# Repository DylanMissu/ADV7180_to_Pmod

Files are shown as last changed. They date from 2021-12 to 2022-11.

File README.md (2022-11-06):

# ADV7180_to_Pmod
These are pcb files for an analog camera block interface board based on the adv7180.

This board takes in analog video and outputs a digital ITU-R BT.656 video signal to the pmod ports. This can then be processed by an FPGA or a fast enough processor.

## Schematic

Schematic for the video converter.
Schematic

## Pictures

| Front | Back |
|---|---|
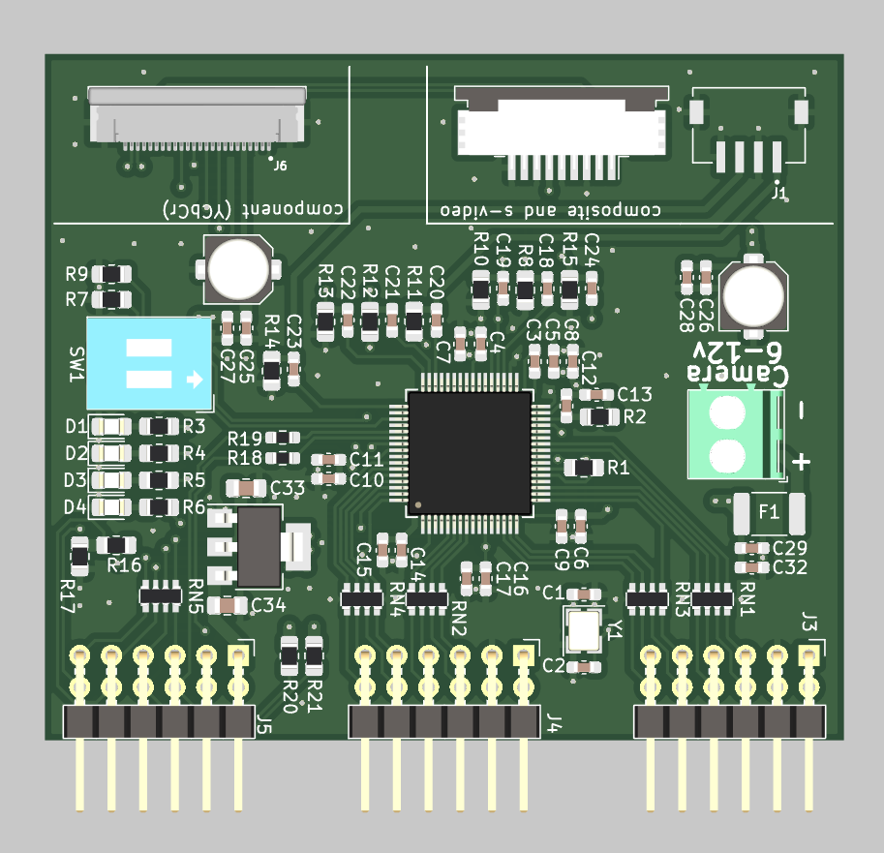
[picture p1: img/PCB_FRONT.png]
front
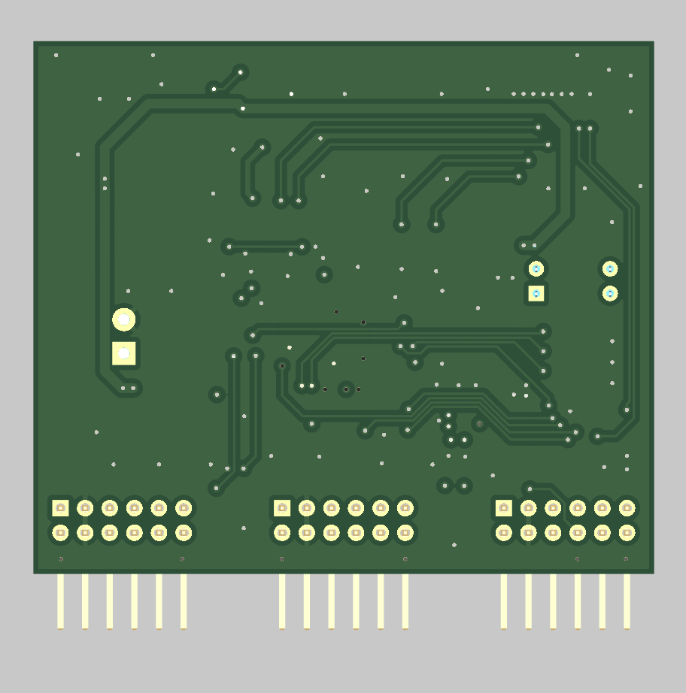
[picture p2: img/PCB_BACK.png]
back
| |  |

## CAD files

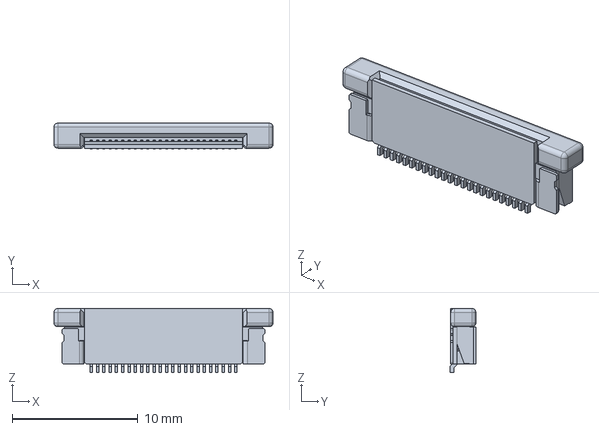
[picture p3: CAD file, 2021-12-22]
footprints/2-1734592-4/2-1734592-4.step
17.4 x 2.05 x 5.11 mm

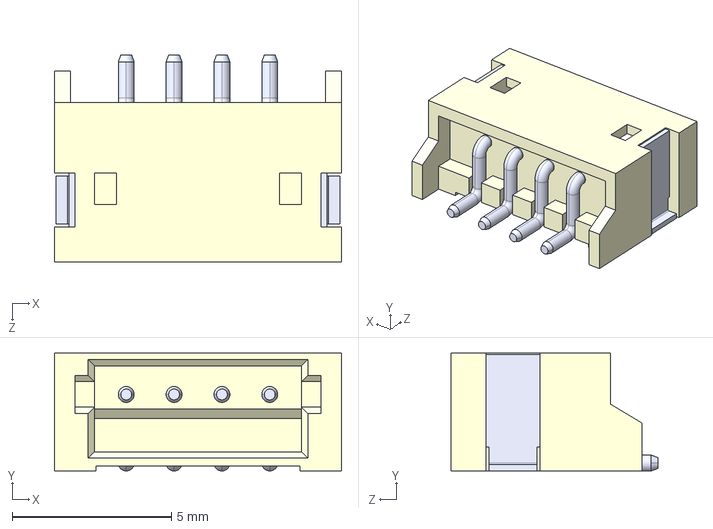
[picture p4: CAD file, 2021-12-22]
step/S4B-ZR-SM4A-TF-LF--SN---3DModel-STEP-56544.STEP
9.00 x 3.70 x 6.50 mm

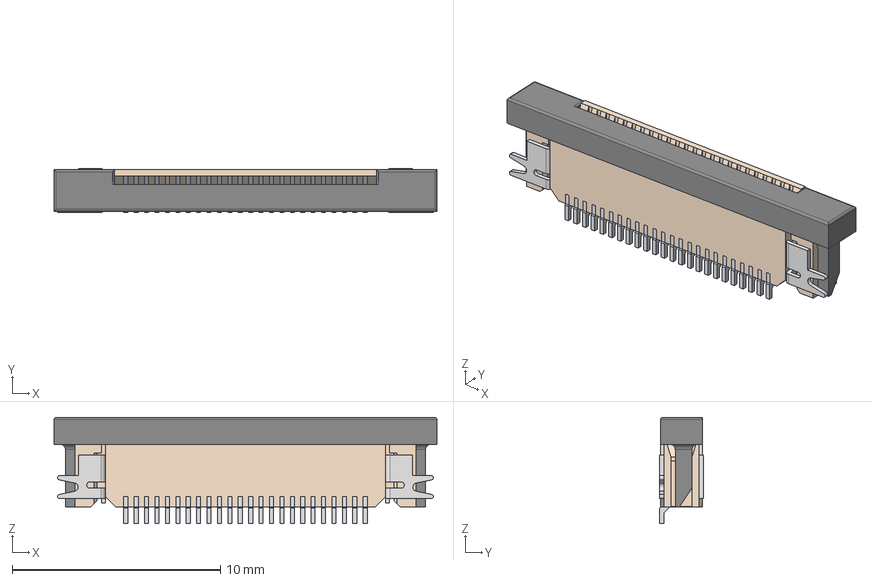
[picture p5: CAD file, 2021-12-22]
step/68712414022.stp
18.4 x 2.10 x 5.10 mm

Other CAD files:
step/2-1734592-4.stp

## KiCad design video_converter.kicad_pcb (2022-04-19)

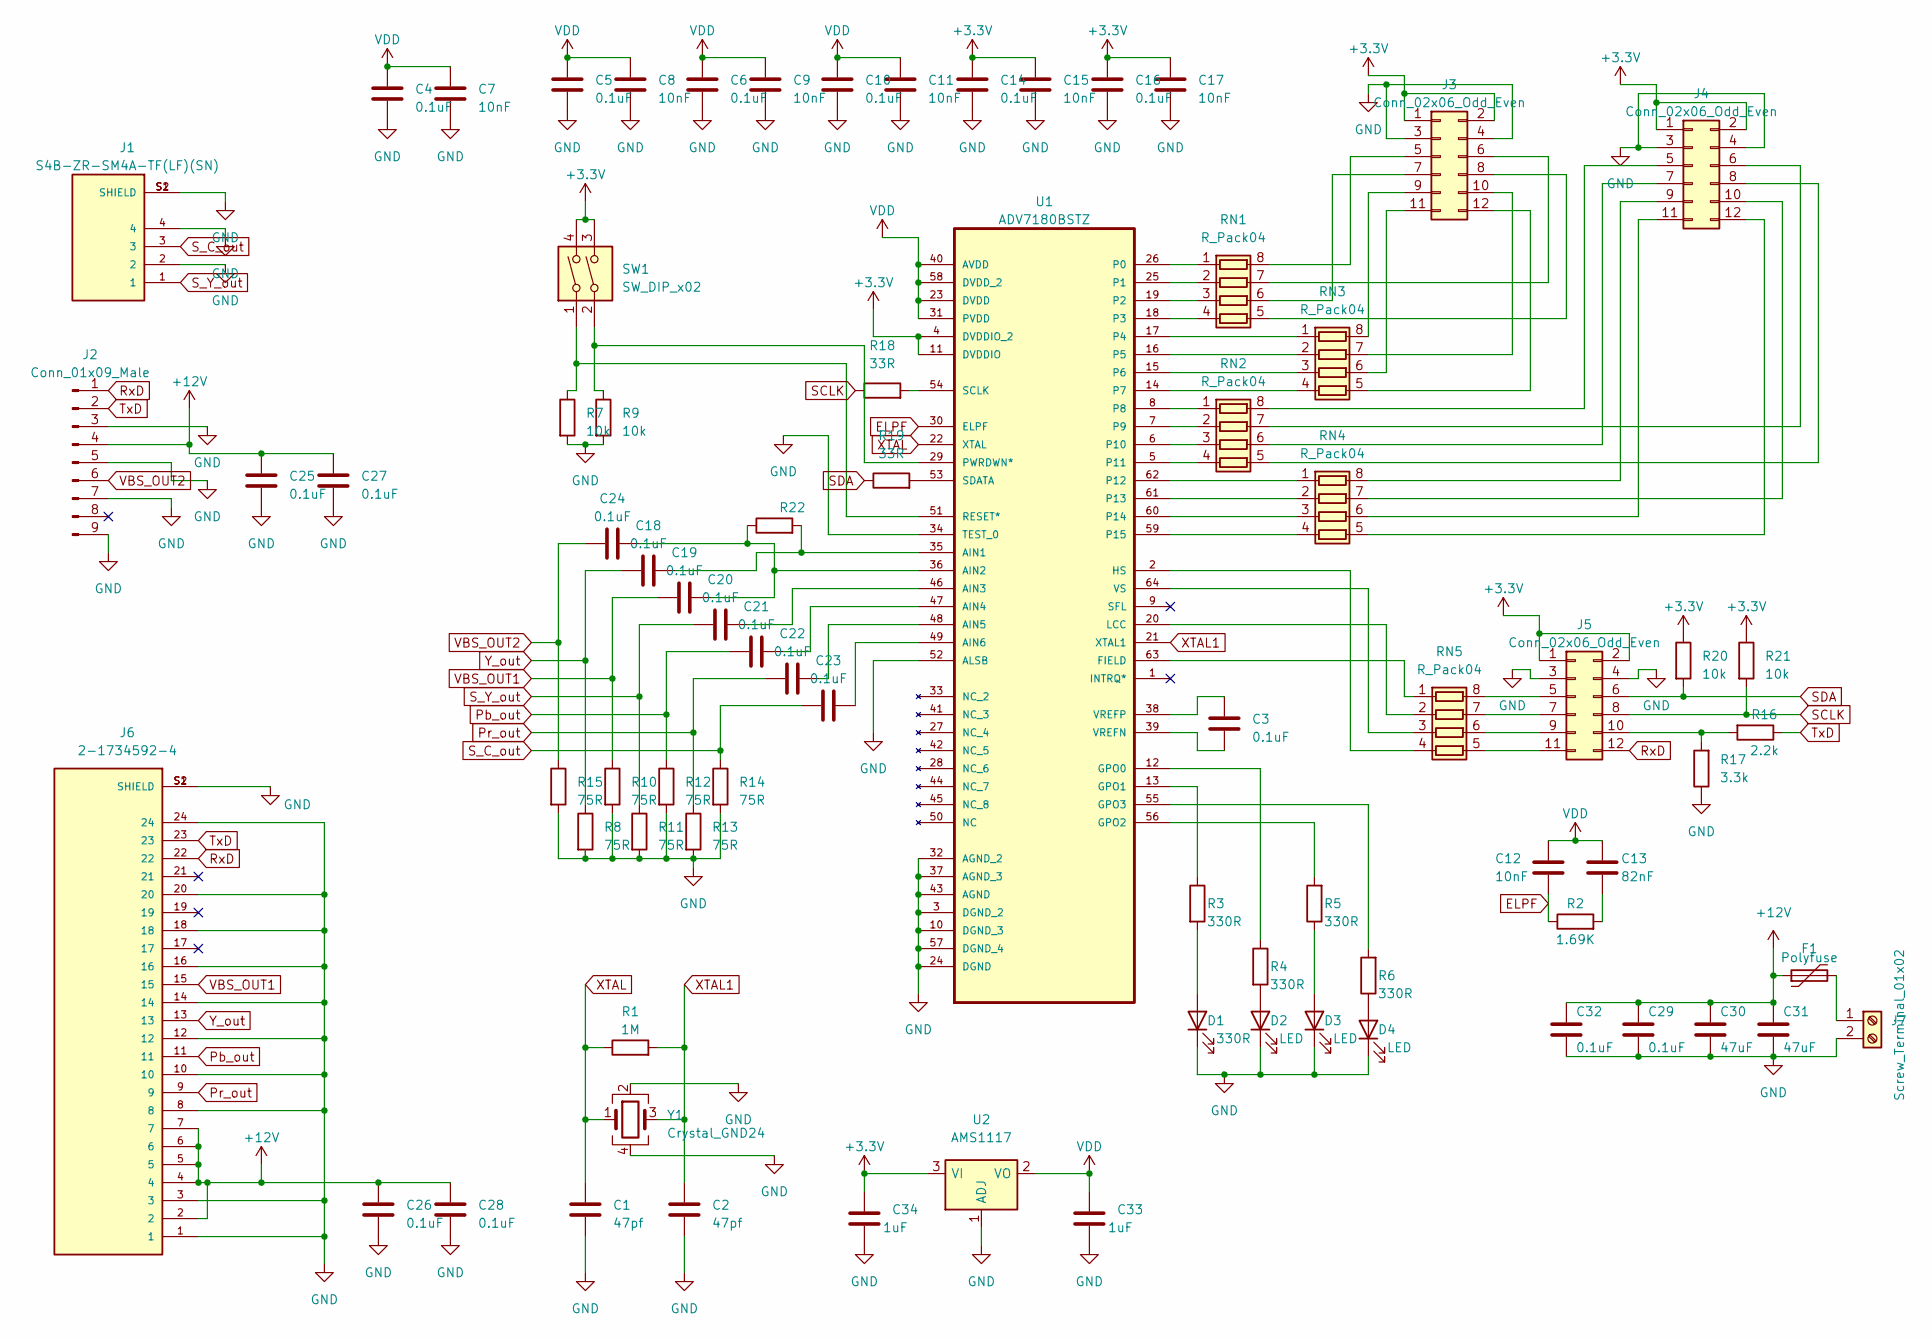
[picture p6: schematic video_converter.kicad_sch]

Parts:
C1, C2: 47pf; C_0603_1608Metric_Pad1.08x0.95mm_HandSolder
C3, C4, C5, C6, C10, C14, C16, C18, C19, C20, C21, C22, C23, C24, C25, C26, C27, C28, C29, C32: 0.1uF; C_0603_1608Metric_Pad1.08x0.95mm_HandSolder
C7, C8, C9, C11, C12, C15, C17: 10nF; C_0603_1608Metric_Pad1.08x0.95mm_HandSolder
C13: 82nF; C_0603_1608Metric_Pad1.08x0.95mm_HandSolder
C30, C31: 47uF; C_Elec_5x5.4
C33, C34: 1uF; C_0805_2012Metric_Pad1.18x1.45mm_HandSolder
D1: 330R; LED_0805_2012Metric_Pad1.15x1.40mm_HandSolder
D2, D3, D4: LED; LED_0805_2012Metric_Pad1.15x1.40mm_HandSolder
F1: Polyfuse; Fuse_1812_4532Metric_Pad1.30x3.40mm_HandSolder
J1: S4B-ZR-SM4A-TF(LF)(SN); JST_S4B-ZR-SM4A-TF(LF)(SN); PARTREV N/A
J2: Conn_01x09_Male; TE_84952-9_1x09-1MP_P1.0mm_Horizontal
J3, J4, J5: Conn_02x06_Odd_Even; PinHeader_2x06_P2.54mm_Horizontal
J6: 2-1734592-4; TE_2-1734592-4; PARTREV C
J7: Screw_Terminal_01x02; TerminalBlock_Phoenix_PT-1,5-2-3.5-H_1x02_P3.50mm_Horizontal
R1: 1M; R_0805_2012Metric_Pad1.20x1.40mm_HandSolder
R2: 1.69K; R_0805_2012Metric_Pad1.20x1.40mm_HandSolder
R3, R4, R5, R6: 330R; R_0805_2012Metric_Pad1.20x1.40mm_HandSolder
R7, R9, R20, R21: 10k; R_0805_2012Metric_Pad1.20x1.40mm_HandSolder
R8, R10, R11, R12, R13, R14, R15: 75R; R_0805_2012Metric_Pad1.20x1.40mm_HandSolder
R16: 2.2k; R_0805_2012Metric_Pad1.20x1.40mm_HandSolder
R17: 3.3k; R_0805_2012Metric_Pad1.20x1.40mm_HandSolder
R18, R19: 33R; R_0603_1608Metric_Pad0.98x0.95mm_HandSolder
R22: (no value)
RN1, RN2, RN3, RN4, RN5: R_Pack04; R_Array_Convex_4x0603
SW1: SW_DIP_x02; SW_DIP_SPSTx02_Slide_9.78x7.26mm_W7.62mm_P2.54mm
U1: ADV7180BSTZ; QFP50P1200X1200X160-64N; MPN ADV7180BSTZ
U2: AMS1117; SOT-223-3_TabPin2
Y1: Crystal_GND24; Crystal_SMD_Abracon_ABM8G-4Pin_3.2x2.5mm

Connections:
+3V3: C14.1, C15.1, C16.1, C17.1, C34.1, J3.1, J3.2, J4.1, J4.2, J5.1, J5.2, R20.1, R21.1, SW1.3, SW1.4, U1.4 (DVDDIO_2), U1.11 (DVDDIO), U2.3 (VI)
+12V: C25.1, C26.1, C27.1, C28.1, C29.1, C30.1, C31.1, C32.1, F1.1, J2.4, J6.2, J6.4, J6.5, J6.6, J6.7
ELPF: C12.1, R2.1, U1.30 (ELPF)
GND: C1.2, C2.2, C4.2, C5.2, C6.2, C7.2, C8.2, C9.2, C10.2, C11.2, C14.2, C15.2, C16.2, C17.2, C25.2, C26.2, C27.2, C28.2, C29.2, C30.2, C31.2, C32.2, C33.2, C34.2, D1.1 (K), D2.1 (K), D3.1 (K), D4.1 (K), J1.2, J1.4, J1.S1 (SHIELD), J1.S2 (SHIELD), J2.3, J2.5, J2.7, J2.9, J3.3, J3.4, J4.3, J4.4, J5.3, J5.4, J6.1, J6.3, J6.8, J6.10, J6.12, J6.14, J6.16, J6.18, J6.20, J6.24, J6.S1 (SHIELD), J6.S2 (SHIELD), J7.2, R7.2, R8.2, R9.2, R10.2, R11.2, R12.2, R13.2, R14.2, R15.2, R17.1, U1.3 (DGND_2), U1.10 (DGND_3), U1.24 (DGND), U1.32 (AGND_2), U1.34 (TEST_0), U1.37 (AGND_3), U1.43 (AGND), U1.52 (ALSB), U1.57 (DGND_4), U2.1 (ADJ), Y1.2, Y1.4
unnamed: C3.1, U1.38 (VREFP)
unnamed: C3.2, U1.39 (VREFN)
unnamed: C13.1, R2.2
unnamed: C18.2, R22.2, U1.35 (AIN1)
unnamed: C19.2, C24.2, R22.1, U1.36 (AIN2)
unnamed: C20.2, U1.46 (AIN3)
unnamed: C21.2, U1.47 (AIN4)
unnamed: C22.2, U1.48 (AIN5)
unnamed: C23.2, U1.49 (AIN6)
unnamed: D1.2 (A), R3.2
unnamed: D2.2 (A), R4.2
unnamed: D3.2 (A), R5.1
unnamed: D4.2 (A), R6.1
unnamed: F1.2, J7.1
unnamed: J3.5, RN1.8 (R1.2)
unnamed: J3.6, RN1.7 (R2.2)
unnamed: J3.7, RN1.6 (R3.2)
unnamed: J3.8, RN1.5 (R4.2)
unnamed: J3.9, RN3.8 (R1.2)
unnamed: J3.10, RN3.7 (R2.2)
unnamed: J3.11, RN3.6 (R3.2)
unnamed: J3.12, RN3.5 (R4.2)
unnamed: J4.5, RN2.8 (R1.2)
unnamed: J4.6, RN2.7 (R2.2)
unnamed: J4.7, RN2.6 (R3.2)
unnamed: J4.8, RN2.5 (R4.2)
unnamed: J4.9, RN4.8 (R1.2)
unnamed: J4.10, RN4.7 (R2.2)
unnamed: J4.11, RN4.6 (R3.2)
unnamed: J4.12, RN4.5 (R4.2)
unnamed: J5.5, RN5.8 (R1.2)
unnamed: J5.7, RN5.7 (R2.2)
unnamed: J5.9, RN5.6 (R3.2)
unnamed: J5.10, R16.2, R17.2
unnamed: J5.11, RN5.5 (R4.2)
unnamed: R3.1, U1.13 (GPO1)
unnamed: R4.1, U1.12 (GPO0)
unnamed: R5.2, U1.56 (GPO2)
unnamed: R6.2, U1.55 (GPO3)
unnamed: R7.1, SW1.1, U1.51 (RESET*)
unnamed: R9.1, SW1.2, U1.29 (PWRDWN*)
unnamed: R18.2, U1.54 (SCLK)
unnamed: R19.2, U1.53 (SDATA)
unnamed: RN1.1 (R1.1), U1.26 (P0)
unnamed: RN1.2 (R2.1), U1.25 (P1)
unnamed: RN1.3 (R3.1), U1.19 (P2)
unnamed: RN1.4 (R4.1), U1.18 (P3)
unnamed: RN2.1 (R1.1), U1.8
unnamed: RN2.2 (R2.1), U1.7 (P9)
unnamed: RN2.3 (R3.1), U1.6 (P10)
unnamed: RN2.4 (R4.1), U1.5 (P11)
unnamed: RN3.1 (R1.1), U1.17 (P4)
unnamed: RN3.2 (R2.1), U1.16 (P5)
unnamed: RN3.3 (R3.1), U1.15 (P6)
unnamed: RN3.4 (R4.1), U1.14 (P7)
unnamed: RN4.1 (R1.1), U1.62 (P12)
unnamed: RN4.2 (R2.1), U1.61 (P13)
unnamed: RN4.3 (R3.1), U1.60 (P14)
unnamed: RN4.4 (R4.1), U1.59 (P15)
unnamed: RN5.1 (R1.1), U1.63 (FIELD)
unnamed: RN5.2 (R2.1), U1.20 (LCC)
unnamed: RN5.3 (R3.1), U1.64 (VS)
unnamed: RN5.4 (R4.1), U1.2 (HS)
Pb_out: C21.1, J6.11, R12.1
Pr_out: C22.1, J6.9, R13.1
RxD: J2.1, J5.12, J6.22
SCLK: J5.8, R18.1, R21.2
SDA: J5.6, R19.1, R20.2
S_C_out: C23.1, J1.3, R14.1
S_Y_out: C20.1, J1.1, R11.1
TxD: J2.2, J6.23, R16.1
VBS_OUT1: C19.1, J6.15, R10.1
VBS_OUT2: C24.1, J2.6, R15.1
VDD: C4.1, C5.1, C6.1, C7.1, C8.1, C9.1, C10.1, C11.1, C12.2, C13.2, C33.1, U1.23 (DVDD), U1.31 (PVDD), U1.40 (AVDD), U1.58 (DVDD_2), U2.2 (VO)
XTAL: C1.1, R1.1, U1.22 (XTAL), Y1.1
XTAL1: C2.1, R1.2, U1.21 (XTAL1), Y1.3
Y_out: C18.1, J6.13, R8.1

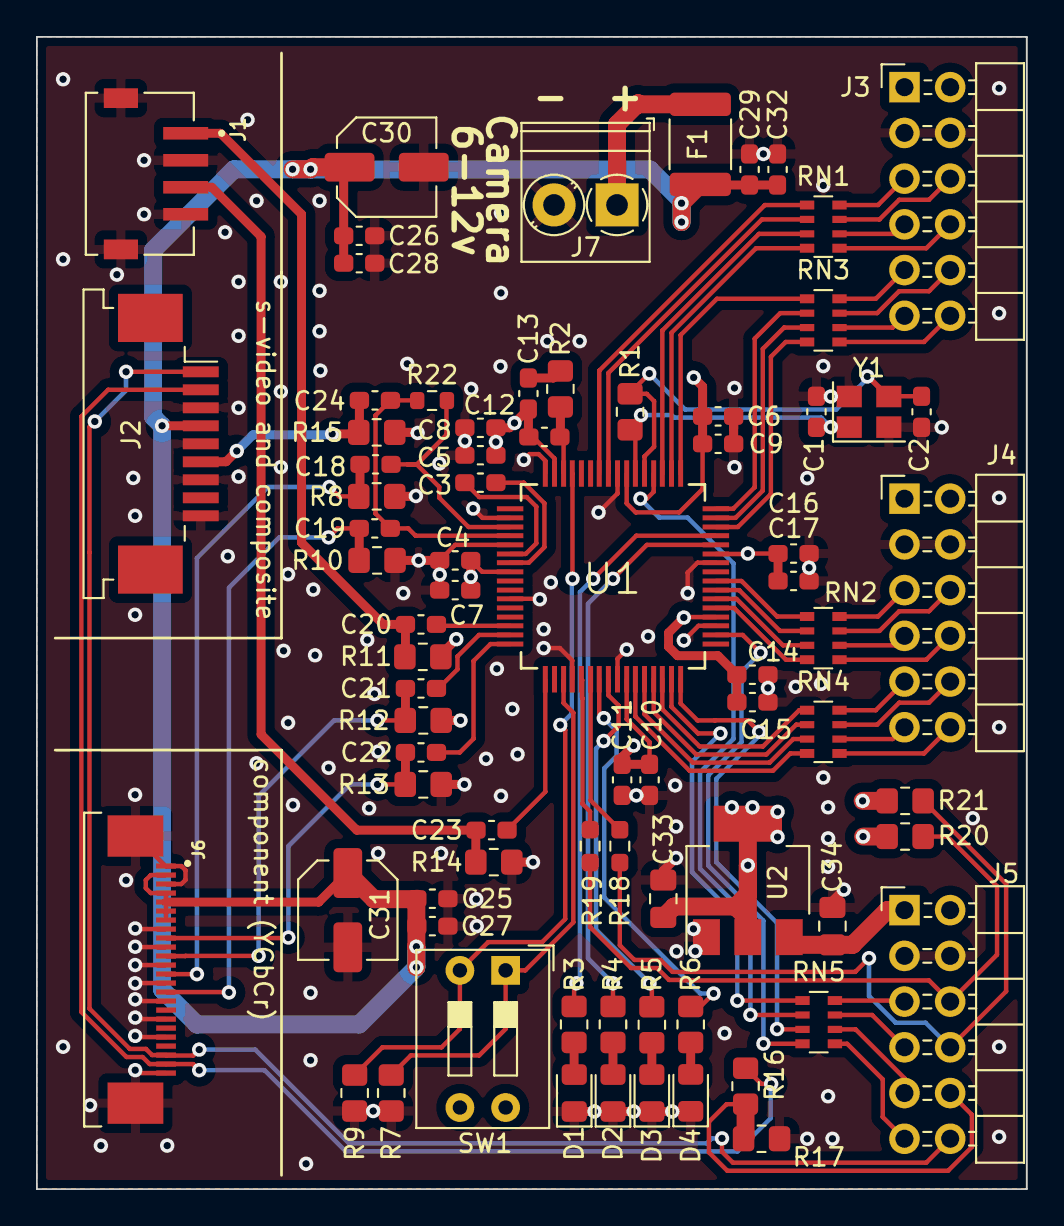
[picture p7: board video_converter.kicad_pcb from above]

Board: 4 copper layers, 55.0 x 64.0 mm, 77 parts (0 on the bottom side), 81 nets.

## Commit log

2022-02-27 updated layout
    [video_converter.kicad_pcb, video_converter.kicad_sch]
2022-04-19 fixed bad routing
    [video_converter.kicad_pcb, video_converter.kicad_sch]
